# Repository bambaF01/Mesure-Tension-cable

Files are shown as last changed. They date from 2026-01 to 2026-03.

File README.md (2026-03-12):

# Tutoriel ESP32 - Mesure de forces par Bluetooth

Ce tutoriel explique le fonctionnement de la lecture des capteurs jusqu'a l'affichage et l'enregistrement.
Système complet de mesure et d'affichage de forces utilisant deux ESP32 communiquant via Bluetooth.

##  Description du projet

Ce projet permet de **mesurer 4 forces en temps réel** à l'aide de capteurs HX711, de les **transmettre sans fil via Bluetooth** à un second ESP32 qui les **affiche sur un écran OLED**, et d'**enregistrer les données sur ordinateur** au format CSV.

### Architecture du système

```
[4x Capteurs HX711] → [ESP32 Maître] → Bluetooth → [ESP32 Esclave] → [Écran OLED]
                                                          ↓
                                                    [USB/Série]
                                                          ↓
                                                    [Ordinateur] → [Fichiers CSV]
```

##  Structure du projet

```
Code_ESP32/
├── README.md                        #  Ce fichier
│
├── ESP32_BT_Emetteur/              #  ESP32 MAÎTRE (émetteur)
│   ├── README.md                    #    Documentation du maître
│   └── ESP32_BT_Emetteur.ino       #    Code Arduino pour lecture HX711 + Bluetooth TX
│
├── ESP32_BT_Recepteur_MAC/         #  ESP32 ESCLAVE (récepteur)
│   ├── README.md                    #    Documentation de l'esclave
│   └── ESP32_BT_Recepteur_MAC.ino  #    Code Arduino pour affichage OLED + Bluetooth RX
│
└── Enregistrement_CSV/             #  Enregistrement des données
    ├── README_APPLICATION.md        #    Guide d'utilisation
    ├── enregistrement_serial.py     #    Script Python d'enregistrement
    ├── requirements.txt             #    Dépendances Python
    ├── lecture_USB_ESP32_mac.command     #  Lanceur macOS
    ├── lecture_USB_ESP32_linux.sh        #  Lanceur Linux
    ├── lecture_USB_ESP32_windows.bat     #  Lanceur Windows
    └── donnees_csv/                 #     Dossier des fichiers CSV enregistrés
```

##  Démarrage rapide

### Étape 1 : Préparer le matériel

**ESP32 Maître (Émetteur)** :
- Connecter 4 capteurs HX711 :
  - HX711_1 → GPIO 34
  - HX711_2 → GPIO 35
  - HX711_3 → GPIO 32
  - HX711_4 → GPIO 33
  - CLK (horloge) → GPIO 18
- Bouton de tare → GPIO 13
- Batterie exterieure pour la recharge

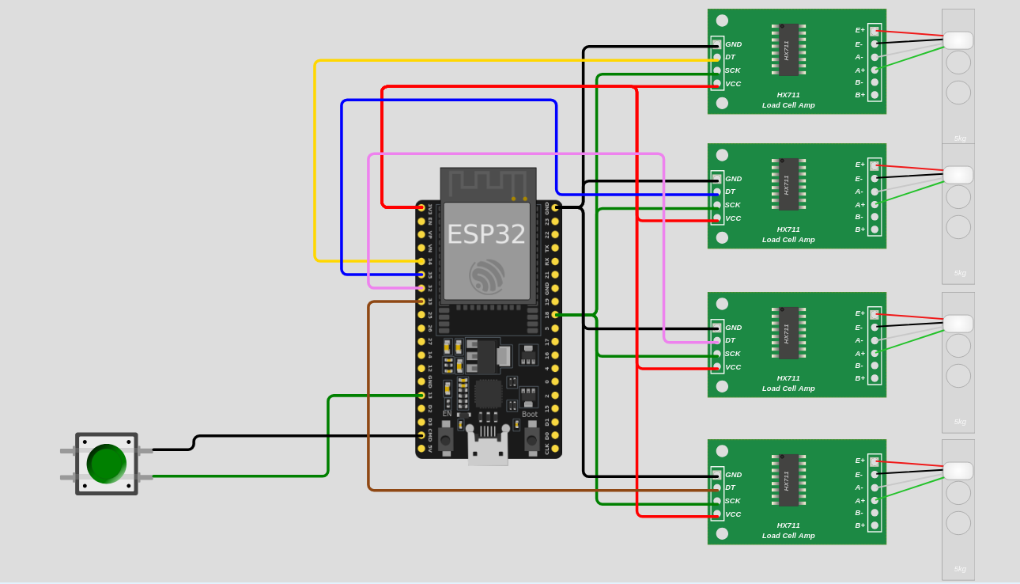
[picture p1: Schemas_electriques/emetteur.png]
Schema emetteur


**ESP32 Esclave (Récepteur)** :
- Écran OLED :
  - SDA → GPIO 21
  - SCL → GPIO 22
- Bouton pause affichage → GPIO 13
- Connexion USB

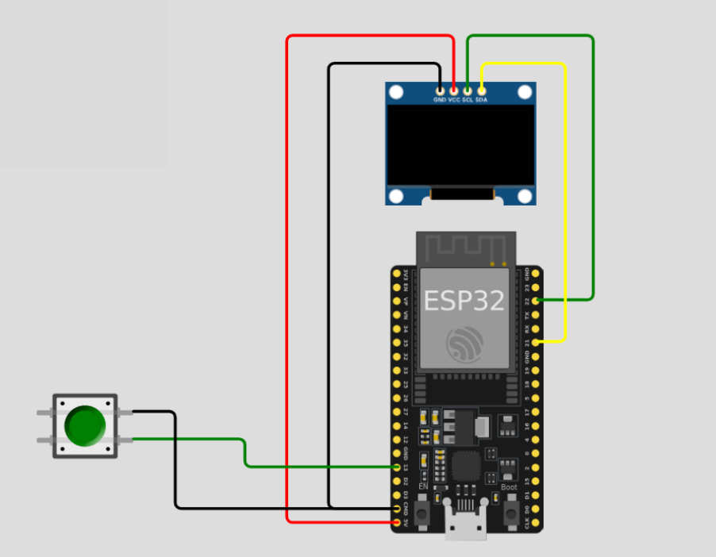
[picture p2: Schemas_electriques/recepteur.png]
Schema recepteur


### Étape 2 : Flasher les ESP32

1. **Installer Arduino IDE** avec support ESP32
2. **Configurer l'IDE Arduino (support ESP32)** :
   - Ouvrir Arduino IDE > **Fichier** > **Préférences**
   - Dans **URL de gestionnaire de cartes supplémentaires**, ajouter `https://dl.espressif.com/dl/package_esp32_index.json`
   - Ouvrir **Outils** > **Type de carte** > **Gestionnaire de cartes...**
   - Rechercher `esp32` et installer **esp32 by Espressif Systems**
   - Sélectionner **Carte** : ESP32 Dev Module 
   - Sélectionner **Port** : le port USB de l'ESP32
   - Régler **Vitesse** : 115200 bauds

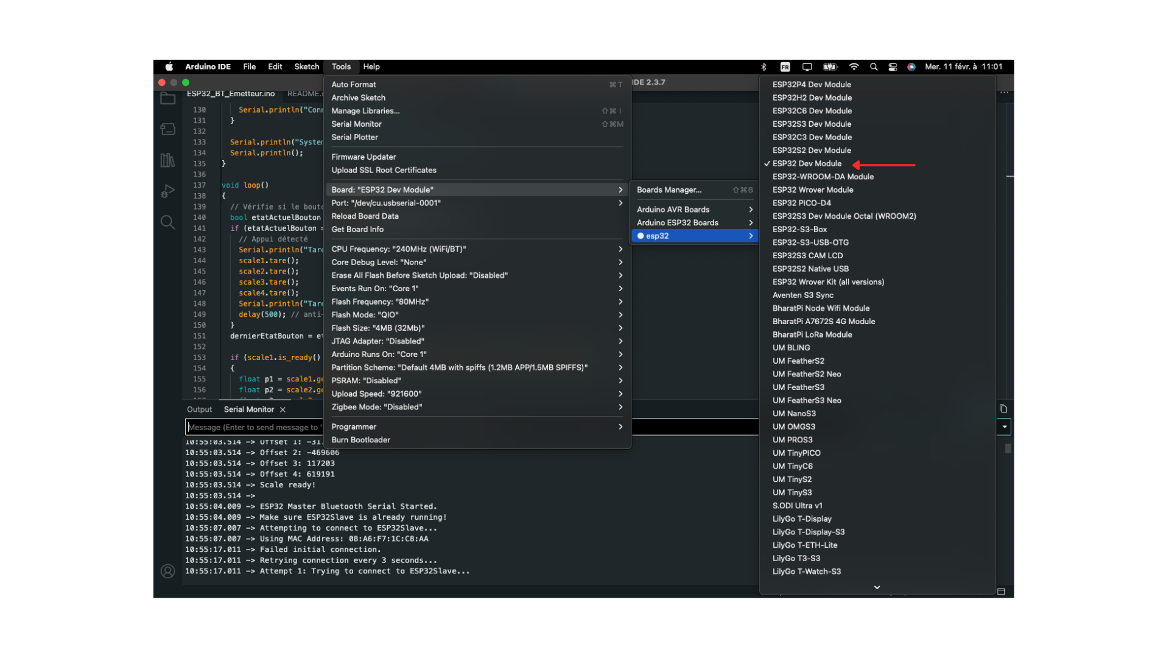
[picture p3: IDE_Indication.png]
Configuration Arduino IDE


3. **Installer les bibliothèques** :
   - `BluetoothSerial` (inclus avec ESP32)
   - `HX711` (par Bogdan Necula)
   - `Adafruit GFX Library`
   - `Adafruit SSD1306`

4. **Flasher l'ESP32 Esclave d'abord** :
   - Ouvrir `ESP32_BT_Recepteur_MAC/ESP32_BT_Recepteur_MAC.ino`
   - Téléverser vers l'ESP32 esclave
   - Ouvrir le Moniteur Série (115200 bauds)
   - **Noter l'adresse MAC Bluetooth** affichée (ex: `8C:4F:00:63:4A:F6`)

5. **Flasher l'ESP32 Maître** :
   - Ouvrir `ESP32_BT_Emetteur/ESP32_BT_Emetteur.ino`
   - **Modifier ligne 28** : remplacer l'adresse MAC par celle de votre esclave :
     ```cpp
     uint8_t slaveMAC[] = {0x8C, 0x4F, 0x00, 0x63, 0x4A, 0xF6};
     ```
   - Téléverser vers l'ESP32 maître

### Étape 3 : Utiliser le système

1. **Allumer l'ESP32 esclave** (récepteur) en premier
2. **Allumer l'ESP32 maître** (émetteur) en deuxiéme
3. La connexion Bluetooth s'établit automatiquement
4. Les 4 forces s'affichent en temps réel sur l'écran OLED
5. Pour enregistrer les données : voir section suivante

### Étape 4 : Enregistrer les données (optionnel)

1. **Installer Python 3** et les dépendances :
   ```bash
   cd Enregistrement_CSV/
   pip install -r requirements.txt
   ```

2. **Lancer l'enregistrement** :
   - **macOS** : double-cliquer sur `lecture_USB_ESP32_mac.command`
   - **Linux** : double-cliquer sur `lecture_USB_ESP32_linux.sh`
   - **Windows** : double-cliquer sur `lecture_USB_ESP32_windows.bat`

3. Les données sont enregistrées dans `Enregistrement_CSV/donnees_csv/`

##  Fonctionnalités détaillées

### ESP32 Maître (Émetteur)

 **Mesure des forces** :
- Lecture de 4 capteurs HX711 simultanément
- Conversion automatique en Newtons (N)
- Tare automatique au démarrage
- Bouton de tare manuel pendant l'utilisation

 **Communication** :
- Mode Bluetooth Maître
- Connexion automatique à l'esclave via adresse MAC
- Reconnexion automatique en cas de perte de signal
- Envoi des 4 forces au format tabulé

 **Calibration** :
- Facteurs de calibration configurables (lignes 12-15)
- Affichage sur Moniteur Série pour débogage

### ESP32 Esclave (Récepteur)

 **Affichage OLED** :
- Écran 128x64 pixels
- Affichage en temps réel des 4 forces (C1, C2, C3, C4)
- Indicateur d'état Bluetooth
- Interface claire et lisible

 **Communication** :
- Mode Bluetooth Esclave
- Affichage de l'adresse MAC au démarrage
- Attente de connexion du maître
- Réception et parsing des données

 **Contrôle** :
- Bouton pour mettre en pause/reprendre l'affichage
- Gestion des erreurs de parsing
- Détection de déconnexion

### Enregistrement CSV

 **Acquisition** :
- Détection automatique du port USB de l'ESP32
- Connexion automatique à 115200 bauds
- Lecture en temps réel des données série

 **Enregistrement** :
- Création automatique du dossier `donnees_csv/`
- Nom de fichier avec horodatage : `donnees_forces_YYYYMMDD_HHMMSS.csv`
- Format CSV standard avec en-têtes

 **Compatibilité** :
- Scripts de lancement pour macOS, Linux et Windows
- Détection automatique du port série
- Pas de configuration manuelle nécessaire

##  Format des données

### Transmission Bluetooth
```
12.34\t23.45\t34.56\t45.67\n
```
(4 valeurs séparées par tabulations, en Newtons)

### Fichiers CSV
```csv
Force_1_N,Force_2_N,Force_3_N,Force_4_N
12.34,23.45,34.56,45.67
12.35,23.46,34.57,45.68
12.36,23.47,34.59,45.69
...
```

##  Prérequis

### Matériel requis

- **2x ESP32 WROOM-32E** (ou compatible)
- **4x modules HX711** avec capteurs de charge/pression
- **1x écran OLED SSD1306** (128x64 pixels, I2C)
- **2x boutons poussoirs** (avec pull-up)
- **Câbles de connexion** et alimentation

### Logiciels requis

**Pour flasher les ESP32** :
- Arduino IDE 1.8+ ou 2.x
- Support ESP32 (via Board Manager)
- Bibliothèques :
  - `BluetoothSerial` (inclus)
  - `HX711` par Bogdan Necula
  - `Adafruit GFX Library`
  - `Adafruit SSD1306`
  - `esp_bt_device` (inclus)

**Pour enregistrer les données** :
- Python 3.7+
- `pyserial` (dans requirements.txt)

##  Configuration et calibration

### Calibration des capteurs HX711

1. Modifier les facteurs de calibration dans `ESP32_BT_Emetteur.ino` (lignes 12-15) :
   ```cpp
   #define SCALE_FACTOR_1 110.95757
   #define SCALE_FACTOR_2 109.68881
   #define SCALE_FACTOR_3 109.27245
   #define SCALE_FACTOR_4 107.75708
   ```

2. Pour recalibrer un capteur :
   - Placer un poids connu (ex: 1 kg)
   - Lire la valeur brute
   - Calculer : `SCALE_FACTOR = valeur_brute / poids_connu`

### Connexion Bluetooth

L'adresse MAC de l'esclave est affichée au démarrage. Pour la modifier dans le maître :
```cpp
uint8_t slaveMAC[] = {0x8C, 0x4F, 0x00, 0x63, 0x4A, 0xF6};
```

##  Dépannage

### Problème : ESP32 maître ne se connecte pas à l'esclave

**Solutions** :
1. Vérifier que l'adresse MAC est correcte dans le code maître
2. S'assurer que l'esclave est démarré AVANT le maître
3. Vérifier les messages dans le Moniteur Série
4. Redémarrer les deux ESP32

### Problème : Écran OLED n'affiche rien

**Solutions** :
1. Vérifier les connexions I2C (SDA=21, SCL=22)
2. Vérifier l'adresse I2C (0x3C par défaut)
3. Tester avec un scanner I2C
4. Vérifier l'alimentation de l'écran

### Problème : Valeurs de force instables

**Solutions** :
1. Appuyer sur le bouton de tare
2. Vérifier les connexions des HX711
3. Recalibrer les capteurs
4. Vérifier l'alimentation (tensions stables)

### Problème : Port USB non détecté

**Solutions** :
1. Installer les pilotes USB CH340/CP2102
2. Vérifier le câble USB 
3. Redémarrer l'ESP32
4. Spécifier manuellement le port dans le script Python

##  Documentation supplémentaire

Consultez les README dans chaque dossier pour plus de détails :

- **[ESP32_BT_Emetteur/README.md](ESP32_BT_Emetteur/README.md)** - Configuration détaillée du maître
- **[ESP32_BT_Recepteur_MAC/README.md](ESP32_BT_Recepteur_MAC/README.md)** - Configuration détaillée de l'esclave 
- **[Enregistrement_CSV/README_APPLICATION.md](Enregistrement_CSV/README_APPLICATION.md)** - Guide complet d'enregistrement

##  Conseils d'utilisation

-  Utiliser une alimentation stable pour les capteurs HX711
-  Effectuer la tare avant chaque série de mesures
-  Laisser les capteurs se stabiliser quelques secondes
-  Les fichiers CSV sont horodatés, aucun risque d'écrasement
-  Le système fonctionne en continu, pas besoin de réinitialiser

##  Notes techniques

- **Bluetooth SPP** : Utilise le profil Serial Port Profile
- **Fréquence** : ~10 mesures/seconde (délai 100ms)
- **Précision** : 2 décimales pour les forces en Newtons
- **Format** : Tabulations pour la transmission, virgules pour le CSV

---

Profitez de votre système de mesure ESP32 !

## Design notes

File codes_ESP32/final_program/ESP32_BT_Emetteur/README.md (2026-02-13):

#  ESP32 Bluetooth Émetteur (Maître)

Code pour l'ESP32 maître qui lit 4 capteurs HX711 et transmet les données via Bluetooth.

##  Description

Cet ESP32 agit comme **maître Bluetooth**. Il :
- Lit 4 capteurs de force HX711
- Convertit les mesures en Newtons
- Transmet les données via Bluetooth à l'esclave
- Affiche les valeurs sur le Moniteur Série
- Permet la tare manuelle via bouton

##  Connexions matérielles

### Capteurs HX711

| HX711 | Broche ESP32 | Signal |
|---|---|---|
| HX711_1 | GPIO 34 | DOUT_1 |
| HX711_2 | GPIO 35 | DOUT_2 |
| HX711_3 | GPIO 32 | DOUT_3 |
| HX711_4 | GPIO 33 | DOUT_4 |
| Tous | GPIO 18 | CLK (horloge) |

### Bouton de tare

| Composant | Broche ESP32 |
|---|---|
| Bouton | GPIO 13 (INPUT_PULLUP) |

### Connexion USB

- Port USB pour alimentation, débogage et enregistrement des données

##  Configuration

### 1. Facteurs de calibration

Modifier les lignes 12-15 selon vos capteurs :

```cpp
#define SCALE_FACTOR_1 110.95757
#define SCALE_FACTOR_2 109.68881
#define SCALE_FACTOR_3 109.27245
#define SCALE_FACTOR_4 107.75708
```

**Pour calibrer** :
1. Placer un poids connu (ex: 1000g)
2. Lire la valeur brute sur le Moniteur Série
3. Calculer : `SCALE_FACTOR = valeur_brute / 1000`

### 2. Adresse MAC de l'esclave

**IMPORTANT** : Remplacer ligne 28 par l'adresse MAC de votre ESP32 esclave :

```cpp
uint8_t slaveMAC[] = {0x8C, 0x4F, 0x00, 0x63, 0x4A, 0xF6};
```

Pour obtenir l'adresse MAC :
1. Flasher et démarrer l'ESP32 esclave
2. Ouvrir le Moniteur Série de l'esclave
3. Noter l'adresse MAC affichée au démarrage

##  Installation

### 1. Bibliothèques requises

Dans Arduino IDE, installer :
- `HX711` par Bogdan Necula (via Library Manager)
- `BluetoothSerial` (inclus avec ESP32)

### 2. Configuration Arduino IDE

Étapes recommandées pour configurer l'IDE :
1. Ouvrir Arduino IDE > **Fichier** > **Préférences**.
2. Dans **URL de gestionnaire de cartes supplémentaires**, ajouter `https://dl.espressif.com/dl/package_esp32_index.json`.
3. Ouvrir **Outils** > **Type de carte** > **Gestionnaire de cartes...**.
4. Rechercher `esp32` et installer **esp32 by Espressif Systems**.
5. Sélectionner **Carte** : ESP32 Dev Module ou WROOM-32E.
6. Sélectionner **Port** : le port USB de l'ESP32.
7. Régler **Vitesse** : 115200 bauds.

Illustration de la configuration :
Configuration Arduino IDE

### 3. Téléversement

1. Modifier l'adresse MAC de l'esclave (ligne 28)
2. Ajuster les facteurs de calibration si nécessaire
3. Compiler et téléverser vers l'ESP32

##  Fonctionnement

### Au démarrage

```
Initializing HX711...
Taring scale... Please ensure no load on sensor.
Tare complete!
Offset 1: 8388607
Offset 2: 8388607
Offset 3: 8388607
Offset 4: 8388607
Scale ready!

ESP32 Master Bluetooth Serial Started.
Make sure ESP32Slave is already running!
Attempting to connect to ESP32Slave...
Using MAC Address: 8C:4F:00:63:4A:F6
Connected to ESP32Slave successfully!
System ready! Starting measurements...
```

### En fonctionnement

Le Moniteur Série affiche continuellement :
```
12.34    23.45    34.56    45.67
12.35    23.46    34.57    45.68
12.36    23.47    34.59    45.69
...
```
(Forces en Newtons, séparées par tabulations)

### Utilisation du bouton de tare

1. Appuyer sur le bouton (GPIO 13)
2. Message : `Tare en cours...`
3. Les 4 capteurs sont remis à zéro
4. Message : `Tare effectuee!`

##  Détails techniques

### Calcul des forces

```cpp
// Lecture brute des capteurs
float p1 = scale1.get_units(1) / sqrt(2.0);

// Conversion en Newtons (masse en kg × g)
float f1 = (p1 / 1000.0) * 9.80665;
```

### Format de transmission Bluetooth

```
F1\tF2\tF3\tF4\n
```
- 4 valeurs séparées par tabulations
- 2 décimales de précision
- Terminé par retour à la ligne

### Gestion de la connexion

- **Connexion automatique** via adresse MAC au démarrage
- **Reconnexion automatique** si déconnexion détectée
- **10 tentatives** avant de redémarrer le Bluetooth
- **Délai de 3 secondes** entre chaque tentative

##  Dépannage

### Problème : "Bluetooth initialization failed!"

**Solutions** :
- Vérifier que le module Bluetooth n'est pas utilisé ailleurs
- Redémarrer l'ESP32
- Vérifier la version de la bibliothèque ESP32

### Problème : "Failed initial connection"

**Solutions** :
1. Vérifier que l'ESP32 esclave est démarré
2. Vérifier l'adresse MAC dans le code
3. Rapprocher les deux ESP32
4. Vérifier les logs de l'esclave

### Problème : "One or more HX711 not ready"

**Solutions** :
- Vérifier les connexions des HX711
- Vérifier l'alimentation des HX711 (3.3V ou 5V)
- Vérifier les broches DOUT et CLK
- Attendre quelques secondes après le démarrage

### Problème : Valeurs instables ou aberrantes

**Solutions** :
1. Effectuer une nouvelle tare
2. Vérifier les câblages
3. Recalibrer les capteurs
4. Améliorer l'alimentation électrique

##  Personnalisation

### Modifier la fréquence d'échantillonnage

Ligne 191 :
```cpp
delay(100);  // Changer à 50, 200, etc. (en ms)
```

### Changer le nombre de lectures moyennées

Ligne 155 :
```cpp
float p1 = scale1.get_units(1);  // Changer 1 à 5, 10, etc.
```
Plus de lectures = plus stable mais plus lent

### Modifier le nom Bluetooth

Ligne 75 :
```cpp
SerialBT.begin("ESP32Master", true);  // Changer le nom
```

##  Conseils

-  Alimenter les HX711 avec une source stable
-  Effectuer la tare au démarrage sans charge
-  Attendre la stabilisation avant les mesures
-  Démarrer l'esclave AVANT le maître
-  Les données sont aussi disponibles via USB série

##  Références

- [Bibliothèque HX711](https://github.com/bogde/HX711)
- [BluetoothSerial ESP32](https://github.com/espressif/arduino-esp32/tree/master/libraries/BluetoothSerial)
- [Datasheet HX711](https://cdn.sparkfun.com/datasheets/Sensors/ForceFlex/hx711_english.pdf)

---

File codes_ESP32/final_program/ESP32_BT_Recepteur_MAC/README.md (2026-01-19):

#  ESP32 Bluetooth Récepteur (Esclave)

Code pour l'ESP32 esclave qui reçoit les données via Bluetooth et les affiche sur un écran OLED.

##  Description

Cet ESP32 agit comme **esclave Bluetooth**. Il :
- Reçoit les données de force via Bluetooth
- Affiche les 4 forces sur un écran OLED
- Affiche l'état de la connexion Bluetooth
- Permet de mettre en pause l'affichage via bouton
- Affiche son adresse MAC au démarrage

##  Connexions matérielles

### Écran OLED SSD1306 (I2C)

| OLED | Broche ESP32 | Signal |
|---|---|---|
| VCC | 3.3V | Alimentation |
| GND | GND | Masse |
| SDA | GPIO 21 | Données I2C |
| SCL | GPIO 22 | Horloge I2C |

**Adresse I2C** : 0x3C (par défaut)  
**Résolution** : 128x64 pixels

### Bouton pause/reprise

| Composant | Broche ESP32 |
|---|---|
| Bouton | GPIO 13 (INPUT_PULLUP) |

### Connexion USB (optionnelle)

- Port USB pour alimentation et débogage
- Pas nécessaire en fonctionnement normal

##  Configuration

### 1. Adresse I2C de l'écran

Si votre écran utilise une adresse différente, modifier ligne 12 :

```cpp
#define SCREEN_ADDRESS 0x3C  // Changer si nécessaire (0x3D parfois)
```

Pour trouver l'adresse I2C :
1. Utiliser un scanner I2C
2. Ou tester 0x3C puis 0x3D

### 2. Nom Bluetooth

Ligne 66 :
```cpp
SerialBT.begin("ESP32Slave", false);  // Modifier le nom si désiré
```

##  Installation

### 1. Bibliothèques requises

Dans Arduino IDE, installer via Library Manager :
- `Adafruit GFX Library`
- `Adafruit SSD1306`
- `BluetoothSerial` (inclus avec ESP32)
- `esp_bt_device` (inclus avec ESP32)

### 2. Configuration Arduino IDE

- **Carte** : ESP32 Dev Module ou WROOM-32E
- **Port** : Sélectionner le port USB de l'ESP32
- **Vitesse** : 115200 bauds

### 3. Téléversement

1. Compiler et téléverser vers l'ESP32
2. Ouvrir le Moniteur Série (115200 bauds)
3. **Noter l'adresse MAC Bluetooth** affichée
4. Utiliser cette adresse dans le code du maître

##  Fonctionnement

### Au démarrage

**Écran OLED affiche** :
```
ESP32Slave
MAC:
  8C:4F:00:63:4A:F6

Waiting for
Master...
```

**Moniteur Série affiche** :
```
ESP32 Slave Bluetooth Serial Started.
Device name: ESP32Slave
Bluetooth MAC Address: 8C:4F:00:63:4A:F6
Bluetooth is discoverable and waiting for connection...
.................
Connected to ESP32_Master successfully!
```

### Pendant la réception

**Écran OLED affiche** :
```
Forces (N):
─────────────────
C1: 12.3    C3: 34.5
C2: 23.4    C4: 45.6

BT: Connecte
```

**Moniteur Série affiche** :
```
Received data: 12.34    23.45   34.56   45.67
Received data: 12.35    23.46   34.57   45.68
...
```

### Utilisation du bouton pause

1. **Appuyer sur le bouton** (GPIO 13)
2. L'affichage se met en pause :
   ```
   
      ARRETE
   
   ```
3. **Appuyer à nouveau** pour reprendre l'affichage

##  Détails techniques

### Format d'affichage OLED

```
┌──────────────────────────┐
│ Forces (N):              │ ← En-tête
│ ─────────────────────── │ ← Ligne séparatrice
│ C1: 12.3    C3: 34.5    │ ← Valeurs (1 décimale)
│ C2: 23.4    C4: 45.6    │
│                          │
│ BT: Connecte            │ ← État Bluetooth
└──────────────────────────┘
```

### Parsing des données

```cpp
// Format reçu : "12.34\t23.45\t34.56\t45.67\n"
float f1, f2, f3, f4;
sscanf(incomingData.c_str(), "%f\t%f\t%f\t%f", &f1, &f2, &f3, &f4);
```

### Gestion de l'affichage

- **Rafraîchissement** : toutes les 200ms
- **État Bluetooth** : vérifié en continu
- **Perte de connexion** : affichage "-" au lieu des valeurs

### Communication I2C

- **Protocole** : I2C hardware
- **Fréquence** : Standard (100 kHz)
- **Broches** : SDA=21, SCL=22 (défaut ESP32)

##  Dépannage

### Problème : "SSD1306 allocation failed"

**Solutions** :
1. Vérifier les connexions I2C (SDA, SCL, VCC, GND)
2. Vérifier l'adresse I2C (essayer 0x3D si 0x3C ne fonctionne pas)
3. Tester avec un scanner I2C
4. Vérifier que l'écran est bien alimenté (3.3V)
5. Essayer un autre câble ou écran

### Problème : Écran affiche "Waiting for Master..." indéfiniment

**Solutions** :
1. Vérifier que l'ESP32 maître est démarré
2. Vérifier que l'adresse MAC dans le maître est correcte
3. Rapprocher les deux ESP32
4. Redémarrer les deux ESP32 (esclave d'abord)

### Problème : "Parsing error: expected 4 values"

**Solutions** :
- Vérifier le format de données envoyé par le maître
- Vérifier que les 4 valeurs sont bien séparées par tabulations
- Regarder les données brutes dans le Moniteur Série

### Problème : Affichage saccadé ou lent

**Solutions** :
- Modifier le délai de rafraîchissement (ligne 254) :
  ```cpp
  if (millis() - lastDisplayUpdate > 200) {  // Augmenter à 300-500
  ```
- Réduire la fréquence d'envoi du maître

##  Personnalisation

### Modifier la mise en page OLED

Fonction `afficherValeurs()` (lignes 131-192) :

```cpp
// Position des textes
display.setCursor(x, y);  // Modifier x et y

// Taille du texte
display.setTextSize(1);   // 1 = petit, 2 = grand

// Nombre de décimales
display.print(lastForces[0], 1);  // Changer 1 à 0, 2, 3...
```

### Changer le délai de rafraîchissement

Ligne 254 :
```cpp
if (millis() - lastDisplayUpdate > 200) {  // Modifier 200 (en ms)
```

### Modifier le nom Bluetooth

Ligne 66 :
```cpp
SerialBT.begin("ESP32Slave", false);  // Changer le nom
```

### Ajouter plus de valeurs à afficher

1. Augmenter le tableau `lastForces[]`
2. Modifier le parsing (`sscanf`)
3. Adapter l'affichage OLED

##  Conseils

-  L'écran OLED peut rester allumé en permanence
-  Toujours démarrer l'esclave AVANT le maître
-  Le bouton pause économise la vie de l'OLED
-  Le Moniteur Série aide au débogage
-  Noter l'adresse MAC pour la configuration du maître

##  Références

- [Adafruit SSD1306](https://github.com/adafruit/Adafruit_SSD1306)
- [Adafruit GFX](https://github.com/adafruit/Adafruit-GFX-Library)
- [BluetoothSerial ESP32](https://github.com/espressif/arduino-esp32/tree/master/libraries/BluetoothSerial)
- [Datasheet SSD1306](https://cdn-shop.adafruit.com/datasheets/SSD1306.pdf)

##  Améliorations possibles

- Ajouter un graphique des forces en temps réel
- Afficher des statistiques (min, max, moyenne)
- Ajouter des seuils d'alerte visuels
- Mémoriser les valeurs maximales
- Ajouter un mode d'économie d'énergie

---

**Retour au projet** : [README principal](../README.md)

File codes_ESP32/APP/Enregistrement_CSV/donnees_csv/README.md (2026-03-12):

#  Dossier des données CSV

Ce dossier contient tous les fichiers CSV enregistrés lors des sessions de mesure.

##  Format des fichiers

### Nom des fichiers

```
donnees_forces_YYYYMMDD_HHMMSS.csv
```

**Exemple** : `donnees_forces_20251022_152345.csv`

- **YYYYMMDD** : Date (Année-Mois-Jour)
- **HHMMSS** : Heure (Heure-Minute-Seconde)

Chaque session d'enregistrement crée un nouveau fichier unique, aucun risque d'écrasement.

### Structure du fichier CSV

```csv
12.34,23.45,34.56,45.67
12.35,23.46,34.57,45.68
12.36,23.47,34.59,45.69
...
```

**Données** :
- Valeurs séparées par virgules
- Précision : 2 décimales
- Une ligne = une mesure instantanée
- Fréquence : ~10 mesures/seconde

##  Gestion des fichiers

### Création automatique

Le dossier `MesureTension/donnees_csv` est créé automatiquement au premier lancement s'il n'existe pas.

### Emplacement

Linux/macOS :
```
~/MesureTension/donnees_csv/
├── donnees_forces_20251022_141230.csv
├── donnees_forces_20251022_143015.csv
├── donnees_forces_20251022_150542.csv
└── ...
```

Windows :
```
C:\Users\<user>\MesureTension\donnees_csv\
    donnees_forces_20251022_141230.csv
    donnees_forces_20251022_143015.csv
    donnees_forces_20251022_150542.csv
    ...
```

### Conservation

- Les fichiers ne sont jamais écrasés
- Chaque session génère un nouveau fichier
- Pensez à nettoyer régulièrement si nécessaire
- Pas de limite de nombre de fichiers

##  Utilisation des données

### Ouvrir dans Excel / LibreOffice

1. Double-cliquer sur le fichier CSV
2. Les colonnes sont automatiquement séparées
3. Créer des graphiques à partir des données

### Ouvrir dans Python

```python
import pandas as pd

# Charger le fichier
df = pd.read_csv('donnees_forces_20251022_152345.csv')

# Afficher les premières lignes
print(df.head())

# Calculer des statistiques
print(df.describe())

# Tracer les forces
import matplotlib.pyplot as plt
df.plot()
plt.show()
```

### Ouvrir dans MATLAB

```matlab
% Charger le fichier
data = readtable('donnees_forces_20251022_152345.csv');

% Afficher les premières lignes
head(data)

% Tracer les forces
plot(data.Force_1_N)
hold on
plot(data.Force_2_N)
plot(data.Force_3_N)
plot(data.Force_4_N)
legend('Force 1', 'Force 2', 'Force 3', 'Force 4')
xlabel('Échantillon')
ylabel('Force (N)')
```

##  Maintenance

**macOS/Linux** :
```bash
# Supprimer les fichiers de plus de 30 jours
find ~/MesureTension/donnees_csv/ -name "*.csv" -mtime +30 -delete
```

**Windows** :
```batch
# Supprimer manuellement ou utiliser PowerShell
Get-ChildItem -Path "$env:USERPROFILE\\MesureTension\\donnees_csv" -Filter "*.csv" | Where-Object {$_.LastWriteTime -lt (Get-Date).AddDays(-30)} | Remove-Item
```

##  Notes

-  Les fichiers sont créés uniquement pendant l'enregistrement
-  Format CSV standard, compatible avec tous les logiciels
-  Encodage UTF-8 pour compatibilité maximale
-  Ne pas modifier manuellement les fichiers en cours d'écriture

---

**Retour à la documentation** : [README Enregistrement](../README_APPLICATION.md) | [README principal](../../README.md)

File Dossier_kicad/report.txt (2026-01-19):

Info: Processing symbol 'SBC-OLED01V1:'.
Info: Processing symbol 'button1:'.
Info: Processing symbol 'U1:RF_Module:ESP32-WROOM-32D'.
Info: Processing symbol 'U5:Package_SO:SOP-16_3.9x9.9mm_P1.27mm'.
Info: Processing symbol 'U3:Package_SO:SOP-16_3.9x9.9mm_P1.27mm'.
Info: Processing symbol 'U2:Package_SO:SOP-16_3.9x9.9mm_P1.27mm'.
Info: Processing symbol 'U4:Package_SO:SOP-16_3.9x9.9mm_P1.27mm'.
Add net unconnected-(U3-INA--Pad7).
Connected U3 pin 10 to unconnected-(U3-INB+-Pad10).
Add net unconnected-(U3-INB+-Pad10).
Connected U3 pin 16 to GND.
Connected U3 pin 11 to Net-(U1-IO13).
Connected U3 pin 1 to unconnected-(U3-VSUP-Pad1).
Add net unconnected-(U3-VSUP-Pad1).
Connected U3 pin 7 to unconnected-(U3-INA--Pad7).
Add net unconnected-(U3-VFB-Pad4).
Connected U3 pin 9 to unconnected-(U3-INB--Pad9).
Add net unconnected-(U3-INB--Pad9).
Connected U3 pin 6 to unconnected-(U3-VBG-Pad6).
Add net unconnected-(U3-VBG-Pad6).
Connected U3 pin 15 to unconnected-(U3-RATE-Pad15).
Add net unconnected-(U3-BASE-Pad2).
Connected U3 pin 2 to unconnected-(U3-BASE-Pad2).
Add net unconnected-(U3-AVDD-Pad3).
Connected U3 pin 4 to unconnected-(U3-VFB-Pad4).
Add net unconnected-(U3-XO-Pad13).
Connected U3 pin 13 to unconnected-(U3-XO-Pad13).
Added U4 (footprint 'Package_SO:SOP-16_3.9x9.9mm_P1.27mm').
Changed REF** reference designator to U4.
Changed U4 value from SOP-16_3.9x9.9mm_P1.27mm to HX711.
Updated U4 symbol association from  to /c9e60ed3-e187-460d-8413-4b107918d9a2.
Updated U4 fields.
Updated U4 sheetname to 'Root'.
Updated U4 sheetfile to 'esp32-ParallelRobot.kicad_sch'.
Updated U4 footprint filters to 'SOP*3.9x9.9mm*P1.27mm*'.
Add net unconnected-(U4-BASE-Pad2).
Changed REF** reference designator to U3.
Connected U2 pin 12 to Net-(U1-IO17).
Add net unconnected-(U2-VSUP-Pad1).
Connected U2 pin 1 to unconnected-(U2-VSUP-Pad1).
Connected U2 pin 5 to GND.
Add net unconnected-(U2-INB--Pad9).
Connected U2 pin 9 to unconnected-(U2-INB--Pad9).
Connected U2 pin 16 to GND.
Add net unconnected-(U2-INA--Pad7).
Connected U2 pin 7 to unconnected-(U2-INA--Pad7).
Add net unconnected-(U2-INB+-Pad10).
Connected U2 pin 10 to unconnected-(U2-INB+-Pad10).
Add net unconnected-(U2-RATE-Pad15).
Connected U2 pin 15 to unconnected-(U2-RATE-Pad15).
Added U3 (footprint 'Package_SO:SOP-16_3.9x9.9mm_P1.27mm').
Add net unconnected-(U3-RATE-Pad15).
Changed U3 value from SOP-16_3.9x9.9mm_P1.27mm to HX711.
Updated U3 symbol association from  to /0466c26b-4775-40f2-841d-736f6abe641f.
Updated U3 fields.
Updated U3 sheetname to 'Root'.
Updated U3 sheetfile to 'esp32-ParallelRobot.kicad_sch'.
Updated U3 footprint filters to 'SOP*3.9x9.9mm*P1.27mm*'.
Connected U3 pin 5 to GND.
Connected U3 pin 12 to Net-(U1-IO16).
Add net unconnected-(U3-XI-Pad14).
Connected U3 pin 14 to unconnected-(U3-XI-Pad14).
Add net unconnected-(U3-INA+-Pad8).
Connected U3 pin 8 to unconnected-(U3-INA+-Pad8).
Connected U4 pin 3 to unconnected-(U4-AVDD-Pad3).
Connected U3 pin 3 to unconnected-(U3-AVDD-Pad3).
Add net unconnected-(U5-VFB-Pad4).
Updated U5 sheetname to 'Root'.
Updated U5 sheetfile to 'esp32-ParallelRobot.kicad_sch'.
Updated U5 footprint filters to 'SOP*3.9x9.9mm*P1.27mm*'.
Add net unconnected-(U5-AVDD-Pad3).
Connected U5 pin 3 to unconnected-(U5-AVDD-Pad3).
Add net unconnected-(U5-BASE-Pad2).
Connected U5 pin 2 to unconnected-(U5-BASE-Pad2).
Add net unconnected-(U5-RATE-Pad15).
Connected U5 pin 15 to unconnected-(U5-RATE-Pad15).
Add net unconnected-(U5-VBG-Pad6).
Connected U5 pin 6 to unconnected-(U5-VBG-Pad6).
Connected U5 pin 12 to Net-(U1-IO15).
Connected U5 pin 11 to Net-(U1-IO13).
Add net unconnected-(U5-XI-Pad14).
Connected U5 pin 14 to unconnected-(U5-XI-Pad14).
Updated U5 fields.
Connected U5 pin 4 to unconnected-(U5-VFB-Pad4).
Add net unconnected-(U5-INB+-Pad10).
Connected U5 pin 10 to unconnected-(U5-INB+-Pad10).
Add net unconnected-(U5-XO-Pad13).
Connected U5 pin 13 to unconnected-(U5-XO-Pad13).
Connected U5 pin 16 to GND.
Add net unconnected-(U5-INA--Pad7).
Connected U5 pin 7 to unconnected-(U5-INA--Pad7).
Add net unconnected-(U5-INB--Pad9).
Connected U5 pin 9 to unconnected-(U5-INB--Pad9).
Add net unconnected-(U5-VSUP-Pad1).
Connected U5 pin 1 to unconnected-(U5-VSUP-Pad1).
Connected U5 pin 5 to GND.
Add net unconnected-(U5-INA+-Pad8).
Connected U5 pin 8 to unconnected-(U5-INA+-Pad8).
Add net unconnected-(U4-XO-Pad13).
Add net unconnected-(U4-AVDD-Pad3).
Connected U2 pin 14 to unconnected-(U2-XI-Pad14).
Connected U4 pin 12 to Net-(U1-IO14).
Connected U4 pin 11 to Net-(U1-IO13).
Add net unconnected-(U4-RATE-Pad15).
Connected U4 pin 15 to unconnected-(U4-RATE-Pad15).
Add net unconnected-(U4-INB--Pad9).
Connected U4 pin 9 to unconnected-(U4-INB--Pad9).
Connected U4 pin 16 to GND.
Add net unconnected-(U4-XI-Pad14).
Connected U4 pin 14 to unconnected-(U4-XI-Pad14).
Add net unconnected-(U4-INA--Pad7).
Connected U4 pin 7 to unconnected-(U4-INA--Pad7).
Add net unconnected-(U4-INA+-Pad8).
Connected U4 pin 8 to unconnected-(U4-INA+-Pad8).
Connected U4 pin 2 to unconnected-(U4-BASE-Pad2).
Connected U4 pin 13 to unconnected-(U4-XO-Pad13).
Add net unconnected-(U4-INB+-Pad10).
Connected U4 pin 10 to unconnected-(U4-INB+-Pad10).
Add net unconnected-(U4-VBG-Pad6).
Connected U4 pin 6 to unconnected-(U4-VBG-Pad6).
Add net unconnected-(U4-VFB-Pad4).
Connected U4 pin 4 to unconnected-(U4-VFB-Pad4).
Connected U4 pin 5 to GND.
Add net unconnected-(U4-VSUP-Pad1).
Connected U4 pin 1 to unconnected-(U4-VSUP-Pad1).
Added U5 (footprint 'Package_SO:SOP-16_3.9x9.9mm_P1.27mm').
Changed REF** reference designator to U5.
Changed U5 value from SOP-16_3.9x9.9mm_P1.27mm to HX711.
Updated U5 symbol association from  to /530fca0d-12be-42de-96eb-12d210e91b90.
Connected U1 pin 18 to unconnected-(U1-NC-Pad18).
Connected U1 pin 26 to unconnected-(U1-IO4-Pad26).
Add net unconnected-(U1-IO5-Pad29).
Connected U1 pin 29 to unconnected-(U1-IO5-Pad29).
Connected U1 pin 39 to GND.
Add net Net-(U1-IO17).
Connected U1 pin 28 to Net-(U1-IO17).
Add net Net-(U1-IO15).
Connected U1 pin 23 to Net-(U1-IO15).
Add net Net-(SBC-OLED01V1-SCL).
Connected U1 pin 9 to Net-(SBC-OLED01V1-SCL).
Connected U1 pin 39 to GND.
Connected U1 pin 39 to GND.
Connected U1 pin 39 to GND.
Connected U1 pin 39 to GND.
Add net unconnected-(U1-NC-Pad18).
Add net unconnected-(U1-IO4-Pad26).
Connected U1 pin 38 to GND.
Connected U1 pin 39 to GND.
Add net unconnected-(U1-NC-Pad32).
Connected U1 pin 32 to unconnected-(U1-NC-Pad32).
Add net unconnected-(U1-NC-Pad20).
Connected U1 pin 20 to unconnected-(U1-NC-Pad20).
Connected U1 pin 39 to GND.
Add net Net-(U1-IO16).
Connected U1 pin 27 to Net-(U1-IO16).
Add net unconnected-(U1-IO35-Pad7).
Connected U1 pin 7 to unconnected-(U1-IO35-Pad7).
Connected U1 pin 39 to GND.
Connected U1 pin 2 to GND.
Connected U1 pin 39 to GND.
Connected U1 pin 8 to GND.
Added U1 (footprint 'RF_Module:ESP32-WROOM-32D').
Changed REF** reference designator to U1.
Changed U1 value from ESP32-WROOM-32D to ESP32-WROOM-32E.
Updated U1 symbol association from  to /7bf0779a-7177-4a61-aac8-e6d642cfde12.
Updated U1 fields.
Updated U1 sheetname to 'Root'.
Updated U1 sheetfile to 'esp32-ParallelRobot.kicad_sch'.
Updated U1 footprint filters to 'ESP32?WROOM?32D*'.
Add net Net-(U1-IO13).
Connected U1 pin 16 to Net-(U1-IO13).
Add net unconnected-(U1-IO18-Pad30).
Connected U1 pin 30 to unconnected-(U1-IO18-Pad30).
Add net GND.
Connected U1 pin 39 to GND.
Connected U1 pin 39 to GND.
Add net unconnected-(U2-XO-Pad13).
Add net unconnected-(U1-RXD0/IO3-Pad34).
Connected U1 pin 34 to unconnected-(U1-RXD0/IO3-Pad34).
Add net Net-(U1-IO14).
Connected U1 pin 13 to Net-(U1-IO14).
Add net unconnected-(U1-SENSOR_VP-Pad4).
Connected U1 pin 4 to unconnected-(U1-SENSOR_VP-Pad4).
Add net unconnected-(U1-IO2-Pad24).
Connected U1 pin 24 to unconnected-(U1-IO2-Pad24).
Add net unconnected-(U1-NC-Pad19).
Connected U1 pin 19 to unconnected-(U1-NC-Pad19).
Add net unconnected-(U1-IO0-Pad25).
Connected U1 pin 25 to unconnected-(U1-IO0-Pad25).
Add net unconnected-(U1-IO23-Pad37).
Connected U1 pin 37 to unconnected-(U1-IO23-Pad37).
Updated U2 sheetfile to 'esp32-ParallelRobot.kicad_sch'.
Connected U1 pin 12 to GND.
Connected U1 pin 39 to GND.
Add net unconnected-(U1-NC-Pad17).
Connected U1 pin 17 to unconnected-(U1-NC-Pad17).
Add net unconnected-(U1-EN-Pad3).
Connected U1 pin 3 to unconnected-(U1-EN-Pad3).
Connected U1 pin 39 to GND.
Connected U1 pin 39 to GND.
Connected U1 pin 39 to GND.
Added U2 (footprint 'Package_SO:SOP-16_3.9x9.9mm_P1.27mm').
Changed REF** reference designator to U2.
Changed U2 value from SOP-16_3.9x9.9mm_P1.27mm to HX711.
Updated U2 symbol association from  to /896e6db6-3628-4403-8fcf-f964f7c20112.
Updated U2 fields.
Updated U2 sheetname to 'Root'.
Connected U1 pin 21 to unconnected-(U1-NC-Pad21).
Updated U2 footprint filters to 'SOP*3.9x9.9mm*P1.27mm*'.
Add net unconnected-(U2-VBG-Pad6).
Connected U2 pin 6 to unconnected-(U2-VBG-Pad6).
Add net unconnected-(U2-INA+-Pad8).
Connected U2 pin 8 to unconnected-(U2-INA+-Pad8).
Connected U2 pin 11 to Net-(U1-IO13).
Add net unconnected-(U2-VFB-Pad4).
Connected U2 pin 4 to unconnected-(U2-VFB-Pad4).
Add net unconnected-(U2-BASE-Pad2).
Connected U2 pin 2 to unconnected-(U2-BASE-Pad2).
Add net unconnected-(U2-AVDD-Pad3).
Connected U2 pin 3 to unconnected-(U2-AVDD-Pad3).
Add net unconnected-(U2-XI-Pad14).
Connected U2 pin 13 to unconnected-(U2-XO-Pad13).
Add net unconnected-(U1-IO25-Pad10).
Add net unconnected-(U1-NC-Pad21).
Add net unconnected-(U1-IO34-Pad6).
Connected U1 pin 6 to unconnected-(U1-IO34-Pad6).
Connected U1 pin 39 to GND.
Add net unconnected-(U1-IO22-Pad36).
Connected U1 pin 36 to unconnected-(U1-IO22-Pad36).
Connected U1 pin 39 to GND.
Add net unconnected-(U1-IO26-Pad11).
Connected U1 pin 11 to unconnected-(U1-IO26-Pad11).
Add net unconnected-(U1-IO12-Pad14).
Connected U1 pin 14 to unconnected-(U1-IO12-Pad14).
Connected U1 pin 39 to GND.
Connected U1 pin 39 to GND.
Add net unconnected-(U1-NC-Pad22).
Connected U1 pin 39 to GND.
Connected U1 pin 10 to unconnected-(U1-IO25-Pad10).
Connected U1 pin 39 to GND.
Connected U1 pin 39 to GND.
Connected U1 pin 15 to GND.
Connected U1 pin 5 to unconnected-(U1-SENSOR_VN-Pad5).
Add net unconnected-(U1-SENSOR_VN-Pad5).
Connected U1 pin 35 to unconnected-(U1-TXD0/IO1-Pad35).
Add net unconnected-(U1-TXD0/IO1-Pad35).
Connected U1 pin 1 to GND.
Connected U1 pin 31 to unconnected-(U1-IO19-Pad31).
Add net unconnected-(U1-IO19-Pad31).
Connected U1 pin 33 to unconnected-(U1-IO21-Pad33).
Add net unconnected-(U1-IO21-Pad33).
Connected U1 pin 22 to unconnected-(U1-NC-Pad22).
Error: Cannot add SBC-OLED01V1 (no footprint assigned).
Error: Cannot add button1 (no footprint assigned).

Info: Total warnings: 0, errors: 2.

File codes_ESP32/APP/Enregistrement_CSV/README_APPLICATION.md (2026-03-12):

#  Enregistreur ESP32 vers CSV

Scripts de lancement pour enregistrer automatiquement les données ESP32 en CSV.

##  Structure du projet

```
Enregistrement_CSV/
├── lecture_USB_ESP32_mac.command     #  Lanceur macOS
├── lecture_USB_ESP32_linux.sh        #  Lanceur Linux
├── lecture_USB_ESP32_windows.bat     #  Lanceur Windows
├── build_windows_pyinstaller.bat     #  Build .exe Windows (PyInstaller)
├── enregistrement_serial.py          #  Script Python principal
├── gui_enregistrement.py             #  Interface graphique locale
├── make_ico.py                        #  Conversion PNG -> ICO (Windows)
├── requirements.txt                  #  Dépendances Python
├── README_APPLICATION.md             #  Ce fichier
└── donnees_csv/                      #  Exemple de dossier (voir emplacement réel ci-dessous)
    └── README.md
```

##  macOS

**Double-cliquez** sur : **`lecture_USB_ESP32_mac.command`**

Ou depuis le terminal :
```bash
./lecture_USB_ESP32_mac.command
```

---

##  Linux

**Double-cliquez** sur : **`lecture_USB_ESP32_linux.sh`**

Ou depuis le terminal :
```bash
./lecture_USB_ESP32_linux.sh
```

---

##  Windows

**Double-cliquez** sur : **`lecture_USB_ESP32_windows.bat`**

---

##  Windows (EXE PyInstaller)

Pour distribuer un exécutable Windows avec icône :

1.  Ouvrir un terminal **Windows** dans ce dossier
2.  Lancer : **`build_windows_pyinstaller.bat`**
3.  L'exe sera dans **`dist/Mesure-Tension.exe`**

---

##  Fonctionnement

Quand vous lancez l'application :

1.  L'interface graphique se lance directement
1.  Détection automatique du port ESP32
2.  Connexion automatique
3.  Création d'un fichier CSV avec horodatage
4.  Enregistrement en temps réel des 4 forces
5.  Ctrl+C pour arrêter et sauvegarder

---

##  Fonctionnement (GUI)

L'interface graphique permet :

1.  Selection du port serie (auto-detect possible)
2.  Choix du dossier de sortie
3.  Bouton Start pour lancer l'enregistrement
4.  Bouton Stop pour terminer et sauvegarder
5.  Les valeurs recentes s'affichent en direct

---

##  Fichiers CSV générés

**Emplacement** : Tous les fichiers CSV sont automatiquement enregistrés dans le dossier :

- Linux/macOS : `~/MesureTension/donnees_csv`
- Windows : `C:\\Users\\<user>\\MesureTension\\donnees_csv`

**Format** : `donnees_forces_YYYYMMDD_HHMMSS.csv`

**Contenu** :
```csv
12.34,23.45,34.56,45.67
12.35,23.46,34.57,45.68
12.36,23.47,34.59,45.69
...
```

Le dossier est créé automatiquement au premier lancement.

---

##  Conseils

- Les fichiers CSV sont automatiquement enregistrés dans le dossier `MesureTension/donnees_csv` de l'utilisateur
- Les lanceurs fonctionnent sur **n'importe quel ordinateur** sans modification
- La détection de l'ESP32 est automatique, pas besoin de configuration

---

Profitez de votre enregistreur ESP32 !

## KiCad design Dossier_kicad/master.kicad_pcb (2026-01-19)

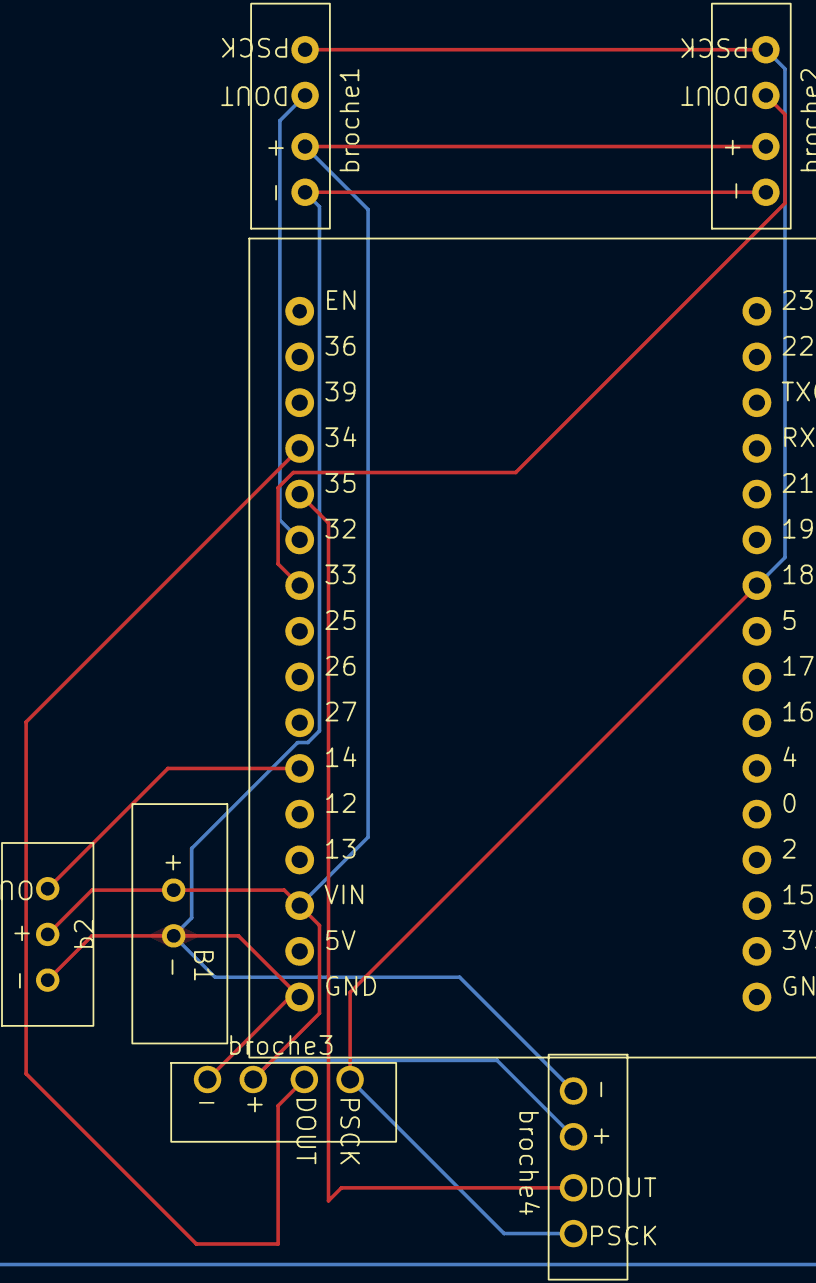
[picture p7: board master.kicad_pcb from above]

Board: 2 copper layers, 7 parts (0 on the bottom side), 7 nets.

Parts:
B1: broche_double
ESP32-WROOM-32E1: ESP32_DevKit_38pin_v2
b2: broche_tri
broche1, broche2, broche3, broche4: TerminalBlock

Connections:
unnamed: B1.1 (+), b2.2 (VCC), broche1.2 (VCC), broche2.2 (VCC), broche3.2 (VCC), broche4.2 (VCC)
unnamed: B1.2 (-), b2.1 (GND), broche1.1 (GND), broche2.1 (GND), broche3.1 (GND), broche4.1 (GND)
unnamed: ESP32-WROOM-32E1.23 (18), broche1.4 (PSCK), broche2.4 (PSCK), broche3.4 (PSCK), broche4.4 (PSCK)
unnamed: ESP32-WROOM-32E1.6 (32), broche1.3 (DOUT)
unnamed: ESP32-WROOM-32E1.7 (33), broche2.3 (DOUT)
unnamed: ESP32-WROOM-32E1.4 (34), broche3.3 (DOUT)
unnamed: ESP32-WROOM-32E1.5 (35), broche4.3 (DOUT)

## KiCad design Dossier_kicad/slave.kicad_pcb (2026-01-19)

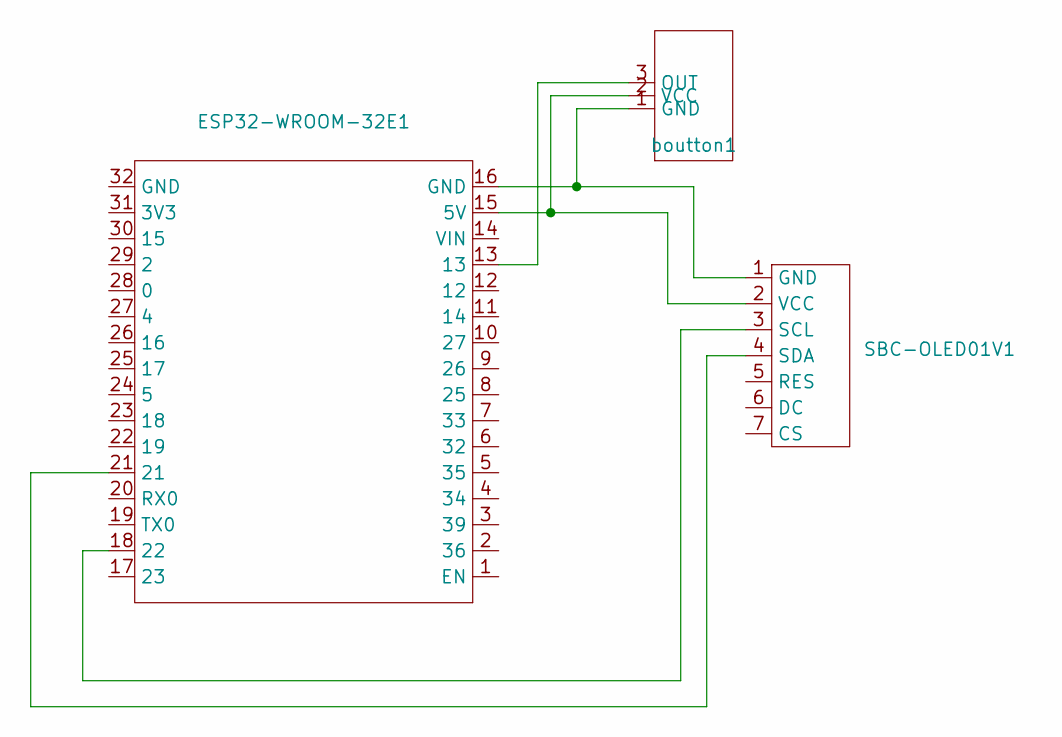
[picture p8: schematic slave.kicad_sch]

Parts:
ESP32-WROOM-32E1: ESP32_DevKit_38pin_v2
SBC-OLED01V1: SBC-OLED01V2
boutton1: broche_tri

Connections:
unnamed: ESP32-WROOM-32E1.15 (5V), SBC-OLED01V1.2 (VCC), boutton1.2 (VCC)
unnamed: ESP32-WROOM-32E1.18 (22), SBC-OLED01V1.3 (SCL)
unnamed: ESP32-WROOM-32E1.16 (GND), SBC-OLED01V1.1 (GND), boutton1.1 (GND)
unnamed: ESP32-WROOM-32E1.21, SBC-OLED01V1.4 (SDA)
unnamed: ESP32-WROOM-32E1.13, boutton1.3 (OUT)

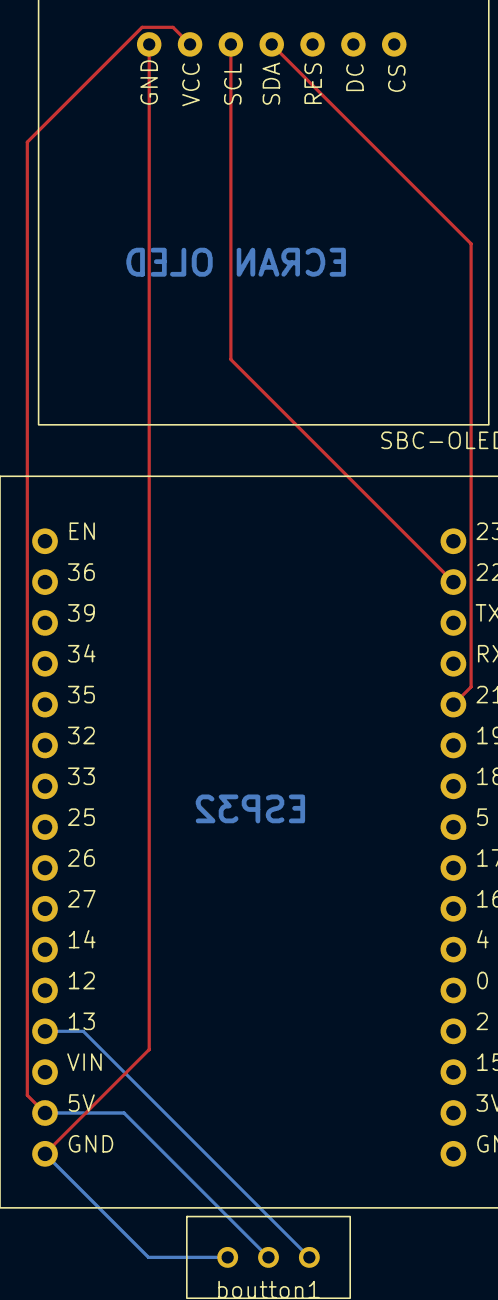
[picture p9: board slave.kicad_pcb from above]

Board: 2 copper layers, 3 parts (0 on the bottom side), 5 nets.

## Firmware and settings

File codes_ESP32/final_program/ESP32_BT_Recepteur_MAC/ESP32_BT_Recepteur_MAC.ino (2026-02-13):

#include <Arduino.h>
#include <BluetoothSerial.h>
#include <esp_bt_device.h>
#include <Wire.h>
#include <Adafruit_GFX.h>
#include <Adafruit_SSD1306.h>

// Configuration de l'écran OLED - SBCOLED01V2
#define SCREEN_WIDTH 128
#define SCREEN_HEIGHT 64
#define OLED_RESET -1  // Broche de réinitialisation (ou -1 si partage avec Arduino)
#define SCREEN_ADDRESS 0x3C  // Adresse I2C pour SBCOLED01V2 (généralement 0x3C)
// Broches I2C pour ESP32 WROOM-32E
#define SDA_PIN 19
#define SCL_PIN 22

// Bouton poussoir pour arrêt d'affichage
#define BOUTON_ARRET 13
bool dernierEtatBoutonArret = HIGH;
bool affichageActif = true;  // État de l'affichage

// Création des objets
BluetoothSerial SerialBT;
Adafruit_SSD1306 display(SCREEN_WIDTH, SCREEN_HEIGHT, &Wire, OLED_RESET);

// Variables
float lastForces[4] = {0.0, 0.0, 0.0, 0.0};
unsigned long lastUpdate = 0;
unsigned long lastDisplayUpdate = 0;
bool hasData = false;


void setup()
{
  // Initialiser la communication série à 115200 bauds pour le débogage
  Serial.begin(115200);
 
  // Attendre un peu pour la connexion du moniteur série
  delay(1000);

  // Initialiser I2C avec les broches personnalisées pour ESP32
  Wire.begin(SDA_PIN, SCL_PIN);
 
  // Initialiser l'écran OLED
  if(!display.begin(SSD1306_SWITCHCAPVCC, SCREEN_ADDRESS)) {
    Serial.println(F("SSD1306 allocation failed"));
    while(1); // Arrêt ici si l'OLED échoue
  }
 
  // Effacer l'écran et afficher le message de démarrage
  display.clearDisplay();
  display.setTextSize(1);
  display.setTextColor(SSD1306_WHITE);
  display.setCursor(0, 0);
  display.println("ESP32 Slave");
  display.println("Initializing...");
  display.display();
  delay(1000);

  // Initialisation bouton d'arrêt
  pinMode(BOUTON_ARRET, INPUT_PULLUP);
  dernierEtatBoutonArret = digitalRead(BOUTON_ARRET);

  // Démarrer la communication Bluetooth et définir le nom "ESP32_Slave"
  // Utiliser un nom sans caractères spéciaux
  if (!SerialBT.begin("ESP32Slave", false)) // false = mode esclave
  {
    Serial.println("Bluetooth initialization failed!");
    display.clearDisplay();
    display.setCursor(0, 0);
    display.println("BT Failed!");
    display.display();
    while(1); // Arrêt ici
  }
 
  Serial.println("ESP32 Slave Bluetooth Serial Started.");
  Serial.println("Device name: ESP32Slave");
 
  // Obtenir et afficher l'adresse MAC Bluetooth
  const uint8_t* mac = esp_bt_dev_get_address();
  Serial.print("Bluetooth MAC Address: ");
  for (int i = 0; i < 6; i++) {
    Serial.printf("%02X", mac[i]);
    if (i < 5) Serial.print(":");
  }
  Serial.println();
 
  // Afficher l'adresse MAC sur l'OLED
  display.clearDisplay();
  display.setCursor(0, 0);
  display.println("ESP32Slave");
  display.println("MAC:");
  display.print("  ");
  for (int i = 0; i < 6; i++) {
    display.printf("%02X", mac[i]);
    if (i < 5) display.print(":");
  }
  display.println();
  display.println();
  display.println("Waiting for");
  display.println("Master...");
  display.display();
 
  Serial.println("Bluetooth is discoverable and waiting for connection...");

  // Attendre jusqu'à ce que le périphérique ESP32 Maître se connecte à cet ESP32 Esclave
  while (!SerialBT.connected())
  {
    delay(1000);  // Attendre 1 seconde avant de vérifier à nouveau
    Serial.print(".");
  }

  // Une fois connecté, afficher un message de confirmation
  Serial.println("");
  Serial.println("Connected to ESP32_Master successfully!");
 
  // Afficher l'état de connexion sur l'OLED
  display.clearDisplay();
  display.setCursor(0, 0);
  display.setTextSize(2);
  display.println("Connected!");
  display.setTextSize(1);
  display.println();
  display.println("Ready to receive");
  display.println("tension data...");
  display.display();
  delay(2000);
}

// Fonction pour afficher les valeurs sur l'OLED
void afficherValeurs() {
  if (!affichageActif) return;
  
  display.clearDisplay();
  display.setTextSize(1);
  display.setCursor(0, 0);
  display.println("Measures:");
  display.drawLine(0, 10, SCREEN_WIDTH, 10, SSD1306_WHITE);
  
  display.setTextSize(2);
  
  // Force 1
  display.setCursor(0, 18);
  if (hasData && SerialBT.connected()) {
    display.print(lastForces[0], 1);
  } else {
    display.print("-");
  }
  
  // Force 2
  display.setCursor(0, 36);
  if (hasData && SerialBT.connected()) {
    display.print(lastForces[1], 1);
  } else {
    display.print("-");
  }
  
  // Force 3
  display.setCursor(64, 18);
  if (hasData && SerialBT.connected()) {
    display.print(lastForces[2], 1);
  } else {
    display.print("-");
  }
  
  // Force 4
  display.setCursor(64, 36);
  if (hasData && SerialBT.connected()) {
    display.print(lastForces[3], 1);
  } else {
    display.print("-");
  }
  
  // État Bluetooth
  display.setTextSize(1);
  display.setCursor(0, 56);
  if (SerialBT.connected()) {
    display.print("BT: Connected");
  } else {
    display.print("BT: Disconnected");
  }
  
  display.display();
}

void loop()
{
  // Vérifie si le bouton d'arrêt d'affichage a été pressé
  bool etatActuelBoutonArret = digitalRead(BOUTON_ARRET);
  if (etatActuelBoutonArret == LOW && dernierEtatBoutonArret == HIGH) {
    // Appui détecté - inverse l'état d'affichage
    affichageActif = !affichageActif;
    if (affichageActif) {
      Serial.println("Display ON");
      // Rafraîchit l'affichage avec les dernières données
      display.clearDisplay();
      display.setTextSize(1);
      display.setCursor(0, 0);
      display.println("Display ON");
      display.display();
    } else {
      Serial.println("OFF");
      // Affiche un message d'arrêt
      display.clearDisplay();
      display.setTextSize(2);
      display.setCursor(10, 20);
      display.println("OFF");
      display.display();
    }
    delay(500); // anti-rebond
  }
  dernierEtatBoutonArret = etatActuelBoutonArret;

  if (SerialBT.available())
  {
    String incomingData = SerialBT.readStringUntil('\n');
    incomingData.trim();

    // N'envoyer au Serial que si l'affichage est actif
    if (affichageActif) {
      Serial.println(incomingData);
    }

    float f1, f2, f3, f4;
    int parsed = sscanf(incomingData.c_str(), "%f\t%f\t%f\t%f", &f1, &f2, &f3, &f4);

    if (parsed == 4)
    {
      lastForces[0] = f1;
      lastForces[1] = f2;
      lastForces[2] = f3;
      lastForces[3] = f4;
      lastUpdate = millis();
      hasData = true;
    }
    else
    {
      Serial.println("Parsing error: expected 4 values.");
    }
  }

  // Vérifier si la connexion est perdue
  if (!SerialBT.connected() && hasData) {
    hasData = false;
  }
  
  // Mettre à jour l'affichage toutes les 200ms
  if (millis() - lastDisplayUpdate > 200) {
    afficherValeurs();
    lastDisplayUpdate = millis();
  }

  delay(50);  // Petit délai pour éviter de surcharger la boucle
}

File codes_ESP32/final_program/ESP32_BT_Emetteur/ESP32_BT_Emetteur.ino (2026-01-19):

#include <Arduino.h>
#include <BluetoothSerial.h>
#include <math.h>
#include "HX711.h"

// Configuration des broches HX711 pour ESP32 WROOM-32E
#define CLK_PIN   18  // Broche d'horloge pour HX711 (SCK)
#define DOUT_PIN_1  34  // Broche de données pour HX711 (MISO)
#define DOUT_PIN_2  35
#define DOUT_PIN_3  32
#define DOUT_PIN_4  33
#define SCALE_FACTOR_1 110.95757 //à determiner
#define SCALE_FACTOR_2 109.68881 //à determiner
#define SCALE_FACTOR_3 109.27245 //à determiner
#define SCALE_FACTOR_4 107.75708 //à determiner

// Bouton poussoir pour tare
#define BOUTON_TARE 13
bool dernierEtatBouton = HIGH;

// Création des objets
BluetoothSerial SerialBT;
HX711 scale1, scale2, scale3, scale4;

// IMPORTANT: Remplacer par l'adresse MAC de votre ESP32 Esclave
// Format: {0xAA, 0xBB, 0xCC, 0xDD, 0xEE, 0xFF}
// Vous l'obtiendrez depuis le Moniteur Série de l'Esclave
uint8_t slaveMAC[] = {0x8C, 0x4F, 0x00, 0x63, 0x4A, 0xF6};

void setup()
{
  Serial.begin(115200);
  
  // Attendre un peu pour la connexion du moniteur série
  delay(1000);

  // Initialiser les capteurs HX711
  Serial.println("Initializing HX711...");
  scale1.begin(DOUT_PIN_1, CLK_PIN);
  scale2.begin(DOUT_PIN_2, CLK_PIN);
  scale3.begin(DOUT_PIN_3, CLK_PIN);
  scale4.begin(DOUT_PIN_4, CLK_PIN);
  
  // Tarer les capteurs (définir le poids actuel comme zéro)
  Serial.println("Taring scale... Please ensure no load on sensor.");
  delay(2000);
  scale1.tare(10);
  scale2.tare(10);
  scale3.tare(10);
  scale4.tare(10);
  Serial.println("Tare complete!");
  Serial.print("Offset 1: ");
  Serial.println(scale1.get_offset());
  Serial.print("Offset 2: ");
  Serial.println(scale2.get_offset());
  Serial.print("Offset 3: ");
  Serial.println(scale3.get_offset());
  Serial.print("Offset 4: ");
  Serial.println(scale4.get_offset());
  
  // Définir le facteur de calibration
  scale1.set_scale(SCALE_FACTOR_1);
  scale2.set_scale(SCALE_FACTOR_2);
  scale3.set_scale(SCALE_FACTOR_3);
  scale4.set_scale(SCALE_FACTOR_4);
  Serial.println("Scale ready!");
  Serial.println();

  // Initialisation bouton
  pinMode(BOUTON_TARE, INPUT_PULLUP);
  dernierEtatBouton = digitalRead(BOUTON_TARE);

  // Démarrer la communication Bluetooth en mode Maître avec le nom "ESP32_Master"
  // Passer 'true' comme deuxième argument active le mode maître
  if (!SerialBT.begin("ESP32Master", true))
  {
    Serial.println("Bluetooth initialization failed!");
    while(1); // Arrêt ici
  }
  
  Serial.println("ESP32 Master Bluetooth Serial Started.");
  Serial.println("Make sure ESP32Slave is already running!");
  
  // Attendre un peu avant de tenter la connexion
  delay(3000);

  // Tentative de connexion au périphérique ESP32 esclave
  Serial.println("Attempting to connect to ESP32Slave...");
  Serial.print("Using MAC Address: ");
  for (int i = 0; i < 6; i++) {
    Serial.printf("%02X", slaveMAC[i]);
    if (i < 5) Serial.print(":");
  }
  Serial.println();
  
  // Tentative de connexion via l'adresse MAC (plus fiable que le nom)
  bool connected = SerialBT.connect(slaveMAC);
  
  if (connected)
  {
    Serial.println("Connected to ESP32Slave successfully!");
  }
  else
  {
    Serial.println("Failed initial connection.");
    Serial.println("Retrying connection every 3 seconds...");
    
    // Réessayer la connexion en boucle
    int attempts = 0;
    while (!SerialBT.connected())
    {
      attempts++;
      Serial.print("Attempt ");
      Serial.print(attempts);
      Serial.println(": Trying to connect to ESP32Slave...");
      
      SerialBT.connect(slaveMAC);
      delay(3000); // Attendre 3 secondes avant de réessayer
      
      if (attempts >= 10)
      {
        Serial.println("Too many failed attempts. Restarting Bluetooth...");
        SerialBT.end();
        delay(1000);
        SerialBT.begin("ESP32Master", true);
        delay(2000);
        attempts = 0;
      }
    }
    Serial.println("Connected to ESP32Slave!");
  }
  
  Serial.println("System ready! Starting measurements...");
  Serial.println();
}

void loop()
{
  // Vérifie si le bouton a été pressé pour lancer la tare
  bool etatActuelBouton = digitalRead(BOUTON_TARE);
  if (etatActuelBouton == LOW && dernierEtatBouton == HIGH) {
    // Appui détecté
    Serial.println("Tare en cours...");
    scale1.tare();
    scale2.tare();
    scale3.tare();
    scale4.tare();
    Serial.println("Tare effectuee!");
    delay(500); // anti-rebond
  }
  dernierEtatBouton = etatActuelBouton;

  if (scale1.is_ready() && scale2.is_ready() && scale3.is_ready() && scale4.is_ready())
  {
    float p1 = scale1.get_units(1);
    float p2 = scale2.get_units(1);
    float p3 = scale3.get_units(1);
    float p4 = scale4.get_units(1);

    float f1 = (p1 / 1000.0) * 9.80665;
    float f2 = (p2 / 1000.0) * 9.80665;
    float f3 = (p3 / 1000.0) * 9.80665;
    float f4 = (p4 / 1000.0) * 9.80665;

    Serial.print(f1, 2); Serial.print("\t");
    Serial.print(f2, 2); Serial.print("\t");
    Serial.print(f4, 2); Serial.print("\t");
    Serial.println(f3, 2);

    if (SerialBT.connected())
    {
      String data = String(f1, 2) + "\t" + String(f2, 2) + "\t" + String(f4, 2) + "\t" + String(f3, 2);
      SerialBT.println(data);
    }
    else
    {
      Serial.println("Warning: Bluetooth disconnected!");
    }
  }
  else
  {
    Serial.println("One or more HX711 not ready.");
  }

  if (SerialBT.available())
  {
    String received = SerialBT.readStringUntil('\n');
    Serial.println("Received from Slave: " + received);
  }

  delay(100);
  
}

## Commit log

2026-01-19 Update force calculation in README
    Removed correction factor for sensor reading in force calculation.
2026-01-19 Remove link to main README from ESP32_BT_Emetteur
    Removed the link to the main README from the ESP32_BT_Emetteur README.
2026-03-12 Add KiCad alim project and CSV GUI
    [alim.kicad_pcb, alim.kicad_sch]
2026-03-12 Add Windows exe build and portable data paths
    [donnees_forces_20260312_103710.csv, donnees_forces_20260312_104305.csv, donnees_forces_20260312_104438.csv]
